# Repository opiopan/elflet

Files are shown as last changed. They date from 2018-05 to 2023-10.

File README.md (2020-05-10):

elflet
====

elflet is a home IoT controller based on [ESP-WROOM-32](https://www.espressif.com/en/products/hardware/modules) (ESP32). <br>
Both of hardware designe and firmware code are open source licenced. 
You are free to use any outcome from this project. And you are also free to modify hardware design and firmware code.<br>
elflet will join your home net work with WiFi.
Then elflet can controll home electronic devices through IR remote controll protocol or Bluetooth LE. 
And this device can be behave as sensor node such as temperature sensor.<br>
Unlike other similar products, elflet highly abstructs IR remote controll protocol. Therefore host-side software to collaborate with elflet is very easy to implement.

<p align="center">
description
</p>

## Features

* **IR receiver**<br>
Receivd IR remote controller signal is analized such as following abstracted protocol data.

    ```json
    {
        "Protocol": "AEHA",
        "BitCount": 160,
        "Data": "11da270002000000000300001000000000000027"
    }
    ```
    Analized protocol data can be retrieved via 
    [REST interface](docs/REST.md), 
    or can be publishd via MQTT protocol.<br>
    **NOTE:** Supported protocols are NEC, SONY, and AEHA.

* **IR transmitter**<br> 
You can transmit IR remote controller signal by specifying the above level abstracted represatation.<br>
elflet supports two protocols for IR transmitter, 
The first one is 
[REST](docs/REST.md)
, and the other one is original binary protocol.
Regarding this binary protocol, please refer 
[these host-side library codes (`irslib.h`, `irslib.c`)](hosttool).

* **Device Shadow**<br>
Device shadow is designed to help complecated IR command device management such as air conditioner.<br>
elflet analize IR command code pattern according to registered shadow definition, then reflect device status to shadow representation managed in elflet. Following JSON data is a example of shadow status representation.
    ```json
    {
        "NodeName": "elflet-living", 
        "ShadowName": "ac",
        "IsOn": true,
        "Attributes":{
            "Mode": "Cooler",
            "Temperature": 26.5,
            "Humidity": 50
        }
    }
    ```

    Shadow status can be refered via 
    [REST interface](docs/REST.md), and status change of shadow device can be known immediately as publicshed data via MQTT.<br>
    You can also change shadow's status by sending the above format data to elflet via 
    [REST interface](docs/REST.md). 
    In this case, elflet synthesize IR code acording to shadow definition then transmit that.<br>
    A couple of shadow definition examples are shown at
    [here](examples).

* **BLE Keyboard Emulator**<br>
elflet can behave as Bluetooth LE (BLE) keyboard. You can send any key code to a device paired with elflet via Bluetooth LE.<br>
The typical use case of this function is to wake up a PC or server which does not accept WOL packet.

* **Environment Sensor**<br>
Following sensors are installed on elflet.
    * temperature sensor
    * humidity sensor
    * atmospheric pressure sensor
    * luminocity sensors

    You can retrieve sensor values via
    [REST interface](docs/REST.md),
    and can also receive them periodically as MQTT published message.<br>
    elflet supports a SENSOR-ONLY mode to avoid own heat affecting to measuring temperature. In this mode, elflet stays in deep sleep status except when sensor values is captured and they are published.
    You can transit elflet to SENSOR-ONLY mode by using
    [host tool](hosttool).

## PCB
PCB of elfet is designed by using [AUTODESK EAGLE](http://eagle.autodesk.com).
* PCB design files are placed [here](pcb/mainboard)
* You can also use [this gerver data](https://raw.githubusercontent.com/wiki/opiopan/elflet/pcb/elflet-mainboard.zip)
for production
* BOM list is [here](pcb/elflet-bom.xlsx?raw=true)

## Building Firmware
Firmware source codes are placed at 
[here](firmware).
To build firmware binary, please refer 
[this document](firmware/README.md).

## Inital Firmware Downloading
Once elflet firmware runs on elflet board, you can download firmware binary via WiFi (OTA updating). However, you need to download firmware via UART at first time since OTA updating function does not work yet.<br>
Folowing four binary files must be download at correct address in ESP-WROOM-32's SPI flash.

|file to download | adress  |
|:---|---:|
| firmware/buld/bootloader/bootloader.bin| 0x1000|
| firmware/buld/partitions.bin | 0x8000|
| firmware/build/ota_data_initial.bin | 0xd000|
| firmware/buld/elflet.bin |  0x10000|
| firmware/buld/spiffsimage.bin | 0x3f0000|

elflet exports sevelal ESP32 pins to service port as below. You can download firmware by connection your USB serial dongle to there.

<p align="center">
description
</p>

Another way to download firmware is using 
[this jig board](https://raw.githubusercontent.com/wiki/opiopan/elflet/pcb/elflet-jig.zip)
and Raspberry Pi. 
[These tools running on Raspberry Pi](raspitools)
may help you to download or debug elflet firmware.<br>
When use this jig board, please connect following direction.

<p align="center">
description
</p>

## Configuration
When initial firmware downloading finish, LED on elflet starts to blink orange. In this state, elflet is working as WiFi access point and it provides Web based setup widzard interface.<br>
The SSID is same as node name of elflet, 
and the initial node name is "`elflet-000000`". Passphrase to connect elflet WiFi access point is same as administorator password, and the initial password is "`elflet00`".
Please connect to elflet WiFi access point by specifing these SSID and passphrase<br>

Once you connect to elflet WiFi access point, you can access to setup widzard. <br>
Since this wizard behaves as same mechanism of [captive portal](https://en.wikipedia.org/wiki/Captive_portal), typical OS shows that wizard window automatically when you connect to elflet WiFi access point.<br>
If no wizard window is shown, try a URL "```http://elflet.setup/```"

**NOTE:** Initial node name and initial administorator password can be change in step of building firmware. Please refer
[this document](firmware/README.md)
regarding the detail. 

<p align="center">
description
</p>

By this wizard, you can configure following items:

* WiFi SSID and passphrase to connect
* elflet node name
* administorator password

When the wizard is completed, elflet restarts and LED start to blink white.
After that, elflet connect to your home network if configuration is correct, and LED turns off.<br>
If WiFi configuration is not correct and elflet cannot connect to your home network in 30 seconds, elflet will fall back to CONFIGURATION mode.
In this case, the LED start to blink orange again and you can access setup Wizard.

During elflet is connecting to your home network, setup widzard is not available. If you want to access setup wizard, please transit elflet to CONFIGURATION mode. You can proceed this transition by pressing a button till LED start to blink orange.

To change other detail configuration, please use a host tools, "`elflet-config`" and "`elflet-shadow`". Usage of these tools are described in [this document](hosttool/README.md).

## Licencing



elflet is released under dual open source licence.<br>
[The elfle firmware](firmware)
is in accordance with 
[GNU General Public License, version 2](https://www.gnu.org/licenses/old-licenses/gpl-2.0.en.html).
The other program source files, PCB design, and all documents are coverd by
[Apache License 2.0](http://www.apache.org/licenses/LICENSE-2.0).

## Application Example
My another project [Wakeserver](https://github.com/opiopan/wakeserver) is a good example of elfelt's application.

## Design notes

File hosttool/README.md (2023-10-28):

elfet Host Tools
===

There are CLI tools to controll elflet as below:

- **elfelt-config**: configure elflet
- **elfelt-shadow**: manage and controll device shadow
- **irtx**: send IR remote controll command

## Requirements
- **Mac or Linux**
- **Python 3**<br>
    ```
    $ python3 --version
    Python 3.7.16
    ```
- **requests** <br>
    ```
    $ pip3 install requests
    ```

## How to install
```
$ make
$ sudo make install
```

## Usage
Run each command with `--help` option. It will show syntax and option's descritption.

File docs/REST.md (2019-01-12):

elflet REST specification
===
**NOTE:** This document is under construction. All interfaces are listed, however descriptions are still insufficient.

## Management

method | path | auth|req-body | resp-body | description
:----|:------:|:-------------:|:------------:|:-------------:|:-----------
GET|/manage/config|none|-|application/json| get elflet configuration
POST|/manage/config|digest|appliation/json|-| change elfelt configuration
GET|/manage/status|none|-|applilcation/json|get statistics and status
POST|/manage/otaupdate|digest|multipart/form|-|update firmware.<br>firmware image is sent as `image` parameta in multipart form.

## IR remote controller
method | path | auth|req-body | resp-body | description
:----|:------:|:-------------:|:------------:|:-------------:|:-----------
GET|/irrc/startReceiver|none|-|-| If `IrrcReceiverMode` parameter of configuration is `OnDemand`, elflet start to receive IR remote controller signal. You can confirm elflet is in this mode as blinking LED blue.<br>If `IrrcReceiverMode` parameter is `Continuous`, This request is ignored.
GET|/irrc/receivedData|none|-|application/json| get latest received IR remote controller code
POST|/irrc/send|none|application/json|-|sedn IR remote controller command

## Device Shadow
method | path | auth|req-body | resp-body | description
:----|:------:|:-------------:|:------------:|:-------------:|:-----------
GET|/shadowDefs|none|-|application/json|list registerd shadow names
GET|/shadowDefs/\<*NAME*>|none|-|application/json|show shadow definition
POST|shadowDefs/\<*NAME*>|digest|application/json|-|add shadow definition
DELETE|shadowDefs/\<*NAME*>|digest|-|-|remove shadow definition
GET|/shadow|none|-|application/json|list registerd shadow names
GET|/shadow/\<*NAME*>|none|-|application/json|get shadow status
POST|/shadow/\<*NAME*>|none|application/json|-|change shadow status

## Sensor

method | path | auth|req-body | resp-body | description
:----|:------:|:-------------:|:------------:|:-------------:|:-----------
GET|/sensor|none|-|application/json| get sonsors value

## BLE keyboard emuration
method | path | auth|req-body | resp-body | description
:----|:------:|:-------------:|:------------:|:-------------:|:-----------
POST|/blehid|none|application/json|-| send key code to a device which paired with elflet BLE keyboard

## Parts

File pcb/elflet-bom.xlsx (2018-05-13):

elflet main board BOM
Label | Attribute | Product id | Quantity | Recommended Seller | URL
U1 | ESP32 module | ESP-WROOM-32 | 1 | Akizuki | http://akizukidenshi.com/catalog/g/gM-11647/
U2 | 3,3V 1A LDO | ADP3338AKCZ-3.3 | 1 |  | http://akizukidenshi.com/catalog/g/gI-12635/
U3 | IR reciever module | OSRB38C9AA | 1 |  | http://akizukidenshi.com/catalog/g/gI-04659/
U4 | Environment sensor | BME280 | 1 | AliExpress | https://www.aliexpress.com/wholesale?SearchText=BME280+chip
Q1 | Nch MOS-FET | IRLML6344TRPBF | 1 | Akizuki | http://akizukidenshi.com/catalog/g/gI-06049/
Q2 | Photo transistor | ALS-PT19-315C/L177/TR8 | 1 | Marutsu | https://www.marutsu.co.jp/GoodsListNavi.jsp?path=&q=ALS-PT19-315C%2FL177%2FTR8
LED1, LED2 | PLCC-2/IR LED | OSI5LAS1C1A | 2 | Akizuki | http://akizukidenshi.com/catalog/g/gI-06427/
LED3 | PLCC-6/Full Color LED | OSTBABS4C2B | 1 |  | http://akizukidenshi.com/catalog/g/gI-06117/
J1 | Micro USB female connector | ZX62-B-5PA(33) | 1 |  | http://akizukidenshi.com/catalog/g/gC-11183/
J2 | low hight pin socket | 2212S-10G-36 | 1 |  | http://akizukidenshi.com/catalog/g/gC-03138/
J3 | NC | - | - | -
SW1 | SMD tact switch | SKRPACE010 | 1 | Akizuki | http://akizukidenshi.com/catalog/g/gP-06185/
C1 | 3216/1uF/25V(+80-20%) | ECJ(L(3))FF1E105Z | 1 |  | http://akizukidenshi.com/catalog/g/gP-08708/
C2 | 3216/4.7uF/16V(+80-20%) | GRM31MF11C475ZA01 | 1 |  | http://akizukidenshi.com/catalog/g/gP-04661/
C3, C5, C8, C9 | 1608/0.1uF/25V(10%) | GRM188B11E104KA01 | 4 |  | http://akizukidenshi.com/catalog/g/gP-05616/
C4, C6 | 1608/10uF/25V(20%) | GRM188R61E106MA | 2 |  | http://akizukidenshi.com/catalog/g/gP-07768/
C7 | 3216/47uF/6.3V(10%) | GRM31CB30J476ME18 | 1 |  | http://akizukidenshi.com/catalog/g/gP-02058/
R1, R2, R3, R6, R10, R14 | 2012/10K/0.1W(0.1%) | AR05BTC1002 | 6 | Sengoku | https://www.sengoku.co.jp/mod/sgk_cart/detail.php?code=EEHD-0HUG
R4, R5 | 1608/4.7K/0.063W/(0.1%) | AR03BTC4701 | 2 |  | https://www.sengoku.co.jp/mod/sgk_cart/detail.php?code=EEHD-0GXT
R7 | 6331/3.3/1W(5%) | RK73BW3ATTE3R3J | 1 |  | https://www.sengoku.co.jp/mod/sgk_cart/detail.php?code=EEHD-0ETM
R8 | 1608/22K/0.063W(0.1%) | AR03BTC2202 | 1 |  | https://www.sengoku.co.jp/mod/sgk_cart/detail.php?code=EEHD-0GYD
R9 | 1608/47/0.063W(0.1%) | AR03BTC0470 | 1 |  | https://www.sengoku.co.jp/mod/sgk_cart/detail.php?code=EEHD-0GW7
R11, R12 | 2012/33/0.1W(0.1%) | AR05BTC0330 | 2 |  | https://www.sengoku.co.jp/mod/sgk_cart/detail.php?code=EEHD-0HSF
R13 | 2012/220/0,1W(0.1%) | AR05BTC2200 | 1 |  | https://www.sengoku.co.jp/mod/sgk_cart/detail.php?code=EEHD-0HT5
R15 | Array 100/0.063W(5%) | BCN164AB101J7 | 1 |  | https://www.sengoku.co.jp/mod/sgk_cart/detail.php?code=6AXT-E7J2
elflet jig BOM
Label | Attribute | Product id | Quantity | Recommended Seller | URL
 | low height pin connector | PH-1x40SG/9.54 | 1 | Akizuki | http://akizukidenshi.com/catalog/g/gC-00171/
 | L type narrow 10 pin header | PHA-1x10RG | 2 |  | http://akizukidenshi.com/catalog/g/gC-06362/
 | 2x20 female pin socket | 2214S-40G-85 | 1 |  | http://akizukidenshi.com/catalog/g/gC-09717/
 | 10 pin female dupont cable | - | 1 | DIY or AliExpress

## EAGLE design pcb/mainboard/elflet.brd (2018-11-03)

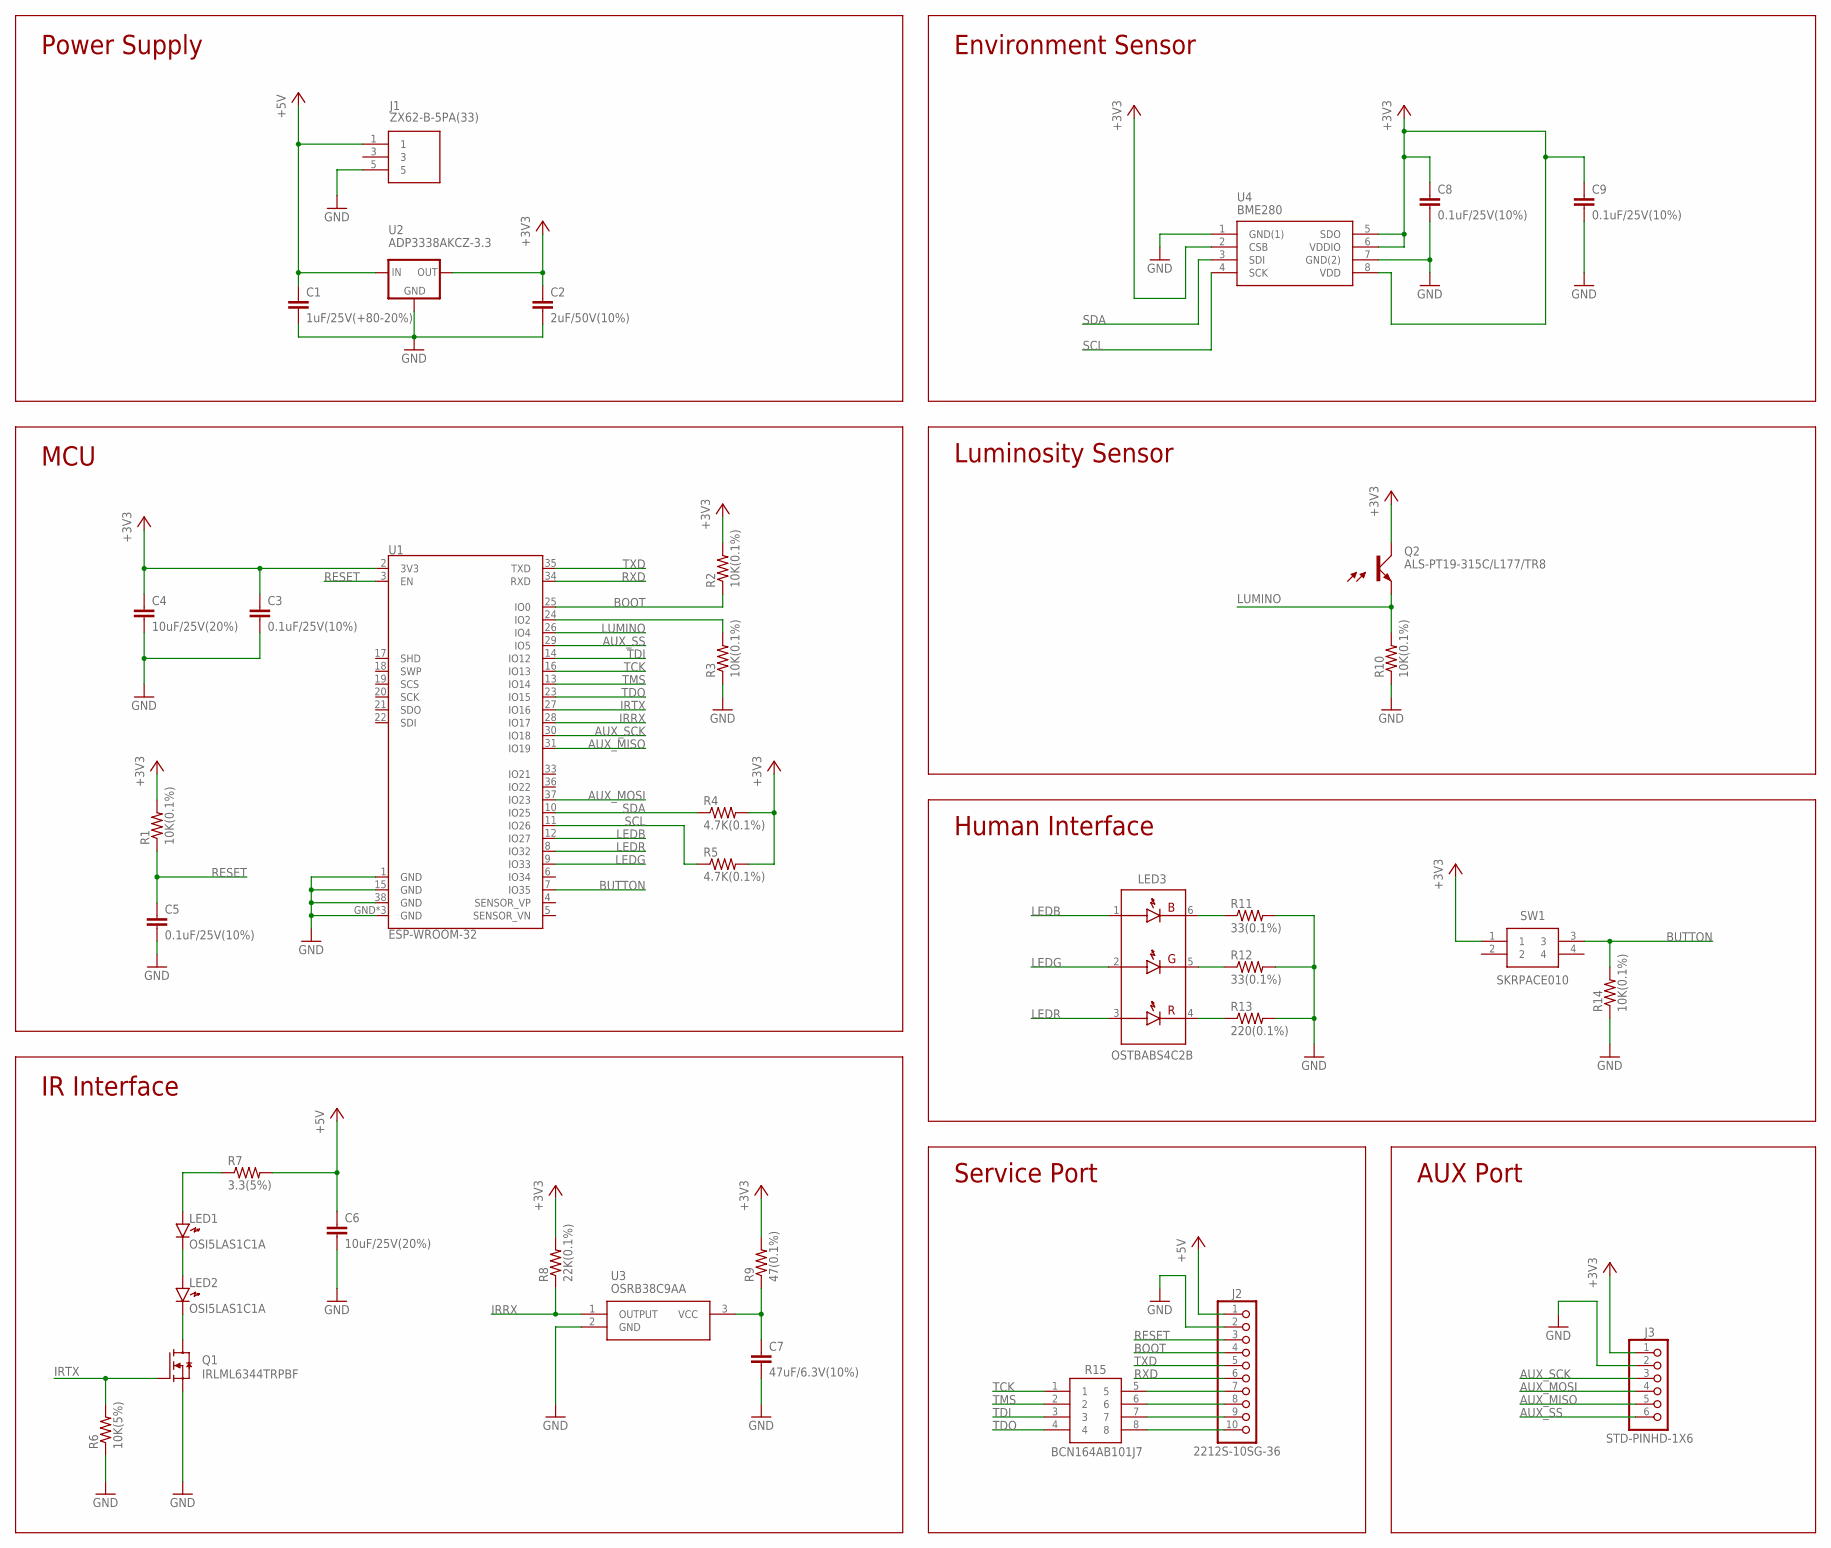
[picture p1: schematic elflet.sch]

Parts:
C1: 1uF/25V(+80-20%); C3216
C2: 2uF/50V(10%); C3216
C3, C5, C8, C9: 0.1uF/25V(10%); C1608
C4, C6: 10uF/25V(20%); C1608
C7: 47uF/6.3V(10%); C3216
J1: ZX62-B-5PA(33); ZX62-B-5PA(33)-TRUE-HANDSOLD
J2: 2212S-10SG-36; STD-1X10
J3: STD-PINHD-1X6; STD-1X6
LED1, LED2: OSI5LAS1C1A; PLCC-2
LED3: OSTBABS4C2B
Q1: IRLML6344TRPBF; SOT23
Q2: ALS-PT19-315C/L177/TR8; ALSPT19315CL177TR8
R1, R2, R3, R10, R14: 10K(0.1%); R0805
R4, R5: 4.7K(0.1%); R0603
R6: 10K(5%); R0805
R7: 3.3(5%); R2512
R8: 22K(0.1%); R0603
R9: 47(0.1%); R0603
R11, R12: 33(0.1%); R0805
R13: 220(0.1%); R0805
R15: BCN164AB101J7; BCN164A_1
SW1: SKRPACE010; SMT(4.2X3.2)
U1: ESP-WROOM-32; ESP-WROOM-03
U2: ADP3338AKCZ-3.3; SOT223
U3: OSRB38C9AA; OSRB38C9AA-ALT
U4: BME280

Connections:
+3V3: C2.1, C3.1, C4.1, C8.1, C9.1, J3.1, Q2.1 (C), R1.2, R2.2, R4.2, R5.2, R8.2, R9.2, SW1.1, U1.2 (3V3), U2.2 (OUT), U2.4 (OUT), U4.2 (CSB), U4.5 (SDO), U4.6 (VDDIO), U4.8 (VDD)
+5V: C1.1, C6.1, J1.1, J2.1, R7.2, U2.3 (IN)
AUX_MISO: J3.5, U1.31 (IO19)
AUX_MOSI: J3.4, U1.37 (IO23)
AUX_SCK: J3.3, U1.30 (IO18)
AUX_SS: J3.6, U1.29 (IO5)
BOOT: J2.4, R2.1, U1.25 (IO0)
BUTTON: R14.2, SW1.3, U1.7 (IO35)
GND: C1.2, C2.2, C3.2, C4.2, C5.2, C6.2, C7.2, C8.2, C9.2, J1.5, J2.2, J3.2, Q1.2 (S), R3.1, R6.1, R10.1, R11.2, R12.2, R13.2, R14.1, U1.1 (GND), U1.15 (GND), U1.38 (GND), U1.GND, U1.GND_B (GND), U1.GND_V (GND), U2.1 (GND), U3.2 (GND), U4.1 (GND(1)), U4.7 (GND(2))
IRRX: R8.1, U1.28 (IO17), U3.1 (OUTPUT)
IRTX: Q1.1 (G), R6.2, U1.27 (IO16)
LEDB: LED3.1 (AB), U1.12 (IO27)
LEDG: LED3.2 (AG), U1.9 (IO33)
LEDR: LED3.3 (AR), U1.8 (IO32)
LUMINO: Q2.2 (E), R10.2, U1.26 (IO4)
unnamed: R3.2, U1.24 (IO2)
unnamed: LED1.1 (K), LED2.2 (A)
unnamed: LED2.1 (K), Q1.3 (D)
unnamed: LED1.2 (A), R7.1
unnamed: C7.1, R9.1, U3.3 (VCC)
unnamed: J2.7, R15.5
unnamed: J2.8, R15.6
unnamed: J2.9, R15.7
unnamed: LED3.6 (KB), R11.1
unnamed: LED3.5 (KG), R12.1
unnamed: LED3.4 (KR), R13.1
unnamed: J2.10, R15.8
RESET: C5.1, J2.3, R1.1, U1.3 (EN)
RXD: J2.6, U1.34 (RXD)
SCL: R5.1, U1.11 (IO26), U4.4 (SCK)
SDA: R4.1, U1.10 (IO25), U4.3 (SDI)
TCK: R15.1, U1.16 (IO13)
TDI: R15.3, U1.14 (IO12)
TDO: R15.4, U1.23 (IO15)
TMS: R15.2, U1.13 (IO14)
TXD: J2.5, U1.35 (TXD)

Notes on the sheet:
MCU
Power Supply
IR Interface
Environment Sensor
Luminosity Sensor
Human Interface
Service Port
AUX Port

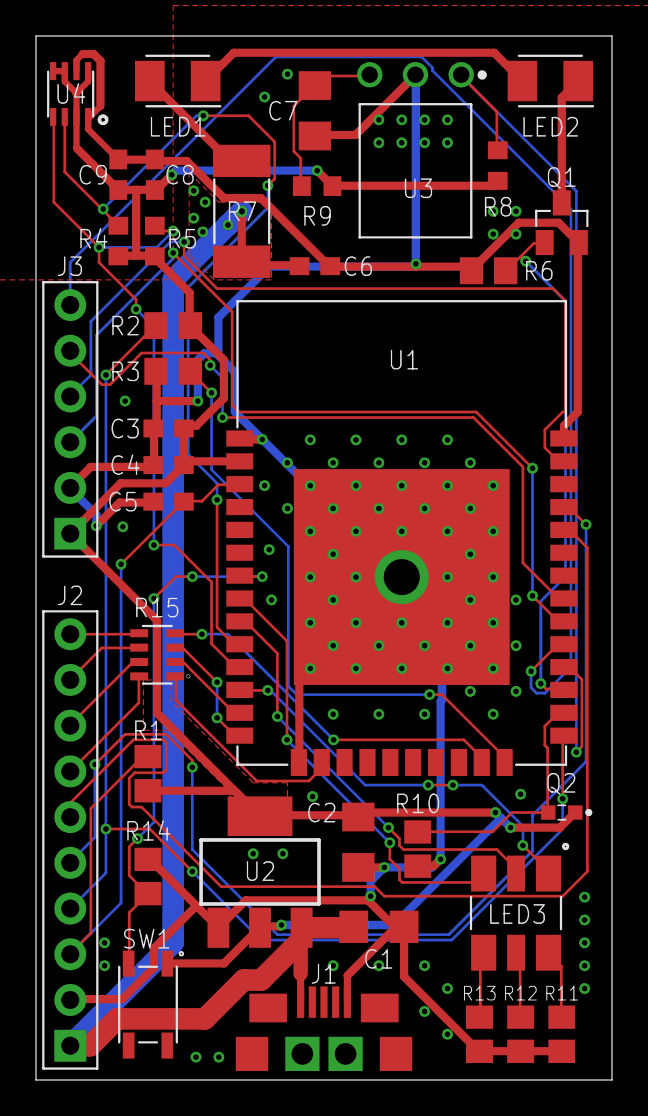
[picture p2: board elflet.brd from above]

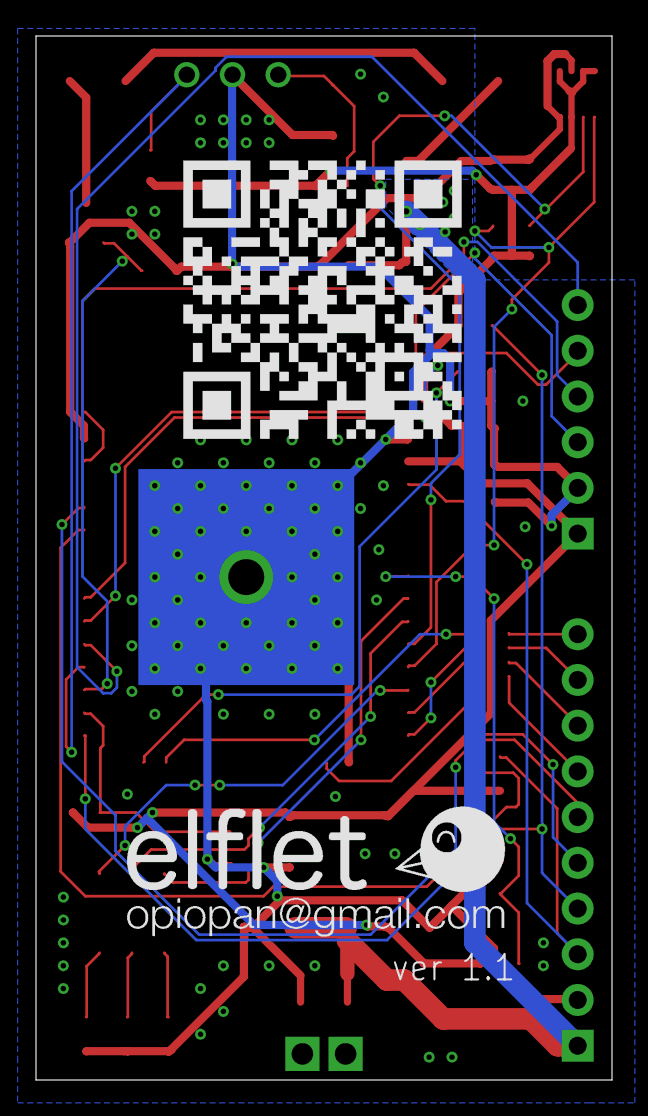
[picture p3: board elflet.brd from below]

Board: 2 copper layers, 32.0 x 58.0 mm, 39 parts (2 on the bottom side), 36 nets.

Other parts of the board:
U$1: ELFLET-LOGO
U$2: ELFLET-QRCODE

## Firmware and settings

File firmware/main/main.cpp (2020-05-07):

#include <esp_log.h>
#include <Task.h>
#include <esp_bt.h>
#include "Config.h"
#include "mdnsService.h"
#include "WifiService.h"
#include "WifiApService.h"
#include "WebService.h"
#include "irserver.h"
#include "LEDService.h"
#include "ButtonService.h"
#include "IRService.h"
#include "SensorService.h"
#include "TimeService.h"
#include "PubSubService.h"
#include "Stat.h"
#include "BleHidService.h"
#include "WatchDog.h"

#include "boardconfig.h"
#include "sdkconfig.h"

static const char tag[] = "main";

_Noreturn static void systemFault(){
    ledSetBlinkMode(LEDBM_SYSTEM_FAULT);
    while (true){
        vTaskDelay(1000 / portTICK_PERIOD_MS);
    }
}

static void showBanner(){
    printf(
        "\033[96m"
        "========================================"
        "========================================\n"
        "        Home IoT controller based on ESP-WROOM-32\n\n"
        "                      ___       ___  ___           __\n"
        "                     /\\_ \\    /'___\\/\\_ \\         /\\ \\__\n"
        "                   __\\//\\ \\  /\\ \\__/\\//\\ \\      __\\ \\ ,_\\ \n"
        "                 /'__`\\\\ \\ \\ \\ \\ ,__\\ \\ \\ \\   /'__`\\ \\ \\/ \n"
        "                /\\  __/ \\_\\ \\_\\ \\ \\_/  \\_\\ \\_/\\  __/\\ \\ \\_ \n"
        "                \\ \\____\\/\\____\\\\ \\_\\   /\\____\\ \\____\\\\ \\__\\ \n"
        "                 \\/____/\\/____/ \\/_/   \\/____/\\/____/ \\/__/ \n\n"
        "        Fiemware Version: %s\n"
        "        Author:           Hiroshi Murayama <opiopan@gmail.com>\n"
        "        Web:              http://github.com/opiopan/elflet/\n"
        "========================================"
        "========================================\n"
        "\033[0m",
        getVersionString());
}

class MainTask : public Task {
    void run(void *data) override;
};

void MainTask::run(void *data){
    updateWatchDog();

    //--------------------------------------------------------------
    // initialize UI LED
    //--------------------------------------------------------------
    startLedService();

    //--------------------------------------------------------------
    // load configuration
    //--------------------------------------------------------------
    if (!initConfig()){
        // nothing to do since serious situation
        systemFault();;
    }

    auto wakeupCause = elfletConfig->getWakeupCause();
    if (wakeupCause != WC_NOTSLEEP){
        baseStat.deepSleepCount++;
        ESP_LOGI(tag, "wakeup from deep sleep by %s",
                 wakeupCause == WC_TIMER ? "time out" : "pushing a button");
    }
    auto mode = elfletConfig->getBootMode();
    ESP_LOGI(tag, "elflet goes to mode: %s",
             mode == Config::FactoryReset ? "FACTORY RESET" :
             mode == Config::Configuration ? "CONFIGURAtiON" :
             "NORMAL");
    if (mode == Config::Configuration){
        elfletConfig->setBootMode(Config::Normal);
        elfletConfig->commit();
    }
    auto isSensorOnly =
        (elfletConfig->getFunctionMode() == Config::SensorOnly);
    auto enableBLE = 
        (wakeupCause == WC_NOTSLEEP && mode == Config::Normal &&
         elfletConfig->getBleHid());

    //--------------------------------------------------------------
    // release memory for Bluetooth if it's possible
    //--------------------------------------------------------------
    if (!enableBLE){
        releaseBleResource();
        auto heapSize = xPortGetFreeHeapSize();
        if (initialHeapSize < heapSize){
            initialHeapSize = heapSize;
            ESP_LOGI(tag, "initial heap size increase to %d bytes", heapSize);
        }
    }
    vTaskDelay(1000 / portTICK_PERIOD_MS);

    //--------------------------------------------------------------
    // start peripheral services
    //--------------------------------------------------------------
    startTimeService();
    startButtonService();
    if (wakeupCause != WC_BUTTON){
        if (!isSensorOnly){
            startIRService();
        }
        startSensorService();
        if (wakeupCause == WC_TIMER){
            enableSensorCapturing();
        }
    }
    
    //--------------------------------------------------------------
    // start network services
    //--------------------------------------------------------------
    if (mode == Config::FactoryReset || mode == Config::Configuration){
        ledSetDefaultMode(
            mode == Config::FactoryReset ? LEDDM_FACTORY_RESET :
                                           LEDDM_CONFIGURATION);
        if (!startWifiApService()){
            systemFault();
        }
        startWebService();
    }else if (!elfletConfig->getWifi()){
        ledSetDefaultMode(LEDDM_BOOT_ONLY_BLE);
        initBleHidService(elfletConfig->getNodeName().c_str());
        startBleHidService();
        vTaskDelay(5000 / portTICK_PERIOD_MS);
        ledSetDefaultMode(LEDDM_STANDBY);
    }else{
        if (wakeupCause == WC_NOTSLEEP){
            ledSetDefaultMode(LEDDM_SCAN_WIFI);
        }else if (wakeupCause == WC_BUTTON){
            ledSetBlinkMode(LEDBM_RESTRICT_DEEP_SLEEP);
        }
        if (elfletConfig->getPubSubServerAddr().length() > 0 &&
            wakeupCause != WC_BUTTON){
            startPubSubService();
        }
        if (!startWifiService()){
            systemFault();
        }
        if (!isSensorOnly || wakeupCause == WC_BUTTON){
            startWebService();
        }
        if (!isSensorOnly){
            startIRServer();
        }
        if (enableBLE){
            initBleHidService(elfletConfig->getNodeName().c_str());
            startBleHidService();
        }
    }

    //--------------------------------------------------------------
    // survey watch dog timer
    //--------------------------------------------------------------
    if (mode == Config::Configuration){
        while (true){
            if (getWatchDogTimerInterval() > 10 * 60){
                ESP_LOGI(tag, "go back to normal mode");
                esp_restart();
            }
            vTaskDelay(1000 / portTICK_PERIOD_MS);
        }
    }
}

extern "C" void app_main() {
    initialHeapSize = xPortGetFreeHeapSize();
    showBanner();
    ESP_LOGI(tag, "free heap size: %d", initialHeapSize);
    auto task = new MainTask;
    task->setStackSize(15000);
    task->start();
}

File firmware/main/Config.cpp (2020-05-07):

#include <esp_log.h>
#include <esp_system.h>
#include <esp_spiffs.h>
#include <nvs_flash.h>
#include <nvs.h>
#include <sys/stat.h>
#include <stdio.h>
#include <iostream>
#include <fstream>
#include <GeneralUtils.h>
#include <CPPNVS.h>
#include <json11.hpp>
#include "Config.h"
#include "ShadowDevice.h"
#include "BleHidJson.h"

#include "boardconfig.h"
#include "sdkconfig.h"

static const char tag[] = "Config";

static const int32_t CONFIG_VERSION = 3;

static const char NVS_NS[] = "elflet";
static const std::string BOOTMODE_KEY = "bootmode";
static const std::string CONFIGGEN_KEY = "configgen";
static const std::string OTACOUNT_KEY = "otacount";

static const char SPIFFS_LABEL[] = "spiffs";
static const char SPIFFS_MP[] = "/spiffs";
static const char VERIFICATION_KEY_PATH[] = "/spiffs/verificationkey.pem";
static const char SHADOW_DEFS_PATH[] = "/spiffs/shadowdefs.json";
static const char TMP_SHADOW_DEFS_PATH[] = "/spiffs/shadowdefs_tmp.json";
static const char SHADOW_STATUS_PATH[] = "/spiffs/shadowstat.json";
static const char* CONFIGPATH[] = {
    "/spiffs/pdata.json",
    "/spiffs/config01.json",
    "/spiffs/config02.json"
};

static const int MAX_NODENAME_LEN = 32;
static const int MAX_PASSWORD_LEN = 64;

const char* Config::defaultTimezone = "JST-9";

Config* elfletConfig = NULL;
static Config* backupedConfig = NULL;
size_t initialHeapSize = 0;

//----------------------------------------------------------------------
// initialize global configuration
//----------------------------------------------------------------------
bool initConfig(){
    // retrieve wakeup cause
    auto wakeupCause = initDeepSleep();
    
    // Initialize NVS
    esp_err_t err = nvs_flash_init();
    if (err == ESP_ERR_NVS_NO_FREE_PAGES) {
        // NVS partition was truncated and needs to be erased
        // Retry nvs_flash_init
        err = nvs_flash_erase();
        if (err != ESP_OK){
            ESP_LOGE(tag, "failed to erase nvs: %s",
                     GeneralUtils::errorToString(err));
            return false;
        }
        err = nvs_flash_init();
    }
    if (err != ESP_OK){
        ESP_LOGE(tag, "failed to initialize nvs: %s",
                 GeneralUtils::errorToString(err));
        return false;
    }

    // mount spiffs
    esp_vfs_spiffs_conf_t conf = {
      .base_path = SPIFFS_MP,
      .partition_label = SPIFFS_LABEL,
      .max_files = 5,
      .format_if_mount_failed = false
    };
    err = esp_vfs_spiffs_register(&conf);
    if (err != ESP_OK){
        ESP_LOGE(tag, "failed to mount spiffs partition: %s",
                 GeneralUtils::errorToString(err));
        return false;
    }
    
    // load configuration
    elfletConfig = new Config(wakeupCause);
    backupedConfig = new Config(wakeupCause);
    return elfletConfig->load();
}

void backupConfig(){
    *backupedConfig = *elfletConfig;
}

void restoreConfig(){
    *elfletConfig = *backupedConfig;
}

//----------------------------------------------------------------------
// Config object initialize / deinitialize
//----------------------------------------------------------------------
Config::Config(WakeupCause cause) :
    fromStorage(false), isDirtyBootMode(false), isDirty(false),
    wakeupCause(cause),
    configVersion(0),
    functionMode(FullSpec), sensorFrequency(0), 
    pubSubSessionType(SessionTCP), irrcReceiverMode(IrrcReceiverOnDemand),
    wifi(true), bleHid(false), buttonMode(BLEHID_KEYCODE){
}

Config::~Config(){
}

Config& Config::operator = (const Config& src){
    otaCount = src.otaCount;
    bootMode = src.bootMode;
    wakeupCause = src.wakeupCause;
    fileGeneration = src.fileGeneration;
    configVersion = src.configVersion;
    functionMode = src.functionMode;
    boardVersion = src.boardVersion;
    nodeName = src.nodeName;
    apssid = src.apssid;
    adminPassword = src.adminPassword;
    ssidToConnect = src.ssidToConnect;
    wifiPassword = src.wifiPassword;
    ntpServer = src.ntpServer;
    timezone = src.timezone;
    sensorFrequency = src.sensorFrequency;
    pubSubServerAddr = src.pubSubServerAddr;
    pubSubSessionType = src.pubSubSessionType;
    pubSubServerCert = src.pubSubServerCert;
    pubSubUser = src.pubSubUser;
    pubSubPassword = src.pubSubPassword;
    sensorTopic = src.sensorTopic;
    irrcReceiveTopic = src.irrcReceiveTopic;
    irrcReceivedDataTopic = src.irrcReceivedDataTopic;
    irrcSendTopic = src.irrcSendTopic;
    downloadFirmwareTopic = src.downloadFirmwareTopic;
    shadowTopic = src.shadowTopic;
    irrcReceiverMode = src.irrcReceiverMode;
    wifi = src.wifi;
    bleHid = src.bleHid;
    buttonMode = src.buttonMode;
    buttonBleHidCode = src.buttonBleHidCode;

    return *this;
}
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

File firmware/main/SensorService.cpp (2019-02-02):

#include <esp_log.h>
#include <esp_system.h>
#include <string.h>
#include <iostream>
#include <GeneralUtils.h>
#include <Task.h>
#include <freertos/event_groups.h>
#include "Mutex.h"
#include "TimeObj.h"
#include "Config.h"
#include "SensorService.h"
#include "bme280.h"
#include "PubSubService.h"
#include "Stat.h"

#include "boardconfig.h"
#include "sdkconfig.h"

static const char tag[] = "SensorService";

class SensorTask;
static SensorTask* sensorTask;

//----------------------------------------------------------------------
// Sensor observation task
//----------------------------------------------------------------------
class SensorTask : public Task {
protected:
    static const int EV_WAKE_SERVER = 1;
    EventGroupHandle_t events;
    Mutex mutex;
    
    BME280_I2C* bme280;

    int enableFlag;
    Time captureTime;

    int32_t temperature;
    int32_t humidity;
    int32_t pressure;
    uint32_t luminosity;

public:
    SensorTask();
    virtual ~SensorTask();

    void enableCapture();
    void getValue(SensorValue* value);

protected:
    void run(void *data) override;
};

SensorTask::SensorTask() : enableFlag(0){
    events = xEventGroupCreate();

    bme280 = new BME280_I2C(0x77,
                            (gpio_num_t)GPIO_I2C_SDA, (gpio_num_t)GPIO_I2C_SCL,
                            I2C::DEFAULT_CLK_SPEED,
                            I2C_NUM_0, false);
    bme280->init();
}

SensorTask::~SensorTask(){
    delete bme280;
}

void SensorTask::enableCapture(){
    xEventGroupSetBits(events, EV_WAKE_SERVER);
}

void SensorTask::getValue(SensorValue* value){
    LockHolder holder(mutex);
    value->enableFlag = enableFlag;
    value->temperature = temperature;
    value->humidity = humidity;
    value->pressure = pressure;
    value->luminosity = luminosity;
}

void SensorTask::run(void *data){
    xEventGroupWaitBits(events, EV_WAKE_SERVER,
                        pdTRUE, pdFALSE,
                        portMAX_DELAY);

    int workingSensors = 0;
    if (bme280->isWorking()){
        workingSensors = 
                SensorValue::TEMPERATURE |
                SensorValue::HUMIDITY |
                SensorValue::PRESSURE;
    }
    
    while (true){
        if (bme280->isWorking()){
            bme280->start(true);
            vTaskDelay(100 / portTICK_PERIOD_MS);
            bme280->measure();
            Time now;
            sensorStat.bme280CaptureCount++;
        }

        {
            LockHolder holder(mutex);
            enableFlag = workingSensors;
            temperature = bme280->getTemperature();
            humidity = bme280->getHumidity();
            pressure = bme280->getPressure();
        }

        publishSensorData();
        
        /*
        printf("%s Temp[%.1f dig] Hum[%.1f %%] Press[%.1f hPa]\n",
               now.format(Time::SIMPLE_DATETIME),
               bme280->getTemperatureFloat(),
               bme280->getHumidityFloat(),
               bme280->getPressureFloat());
        */

        vTaskDelay(
            elfletConfig->getSensorFrequency() * 1000 / portTICK_PERIOD_MS);
    }

    while (true){
    }
};

//----------------------------------------------------------------------
// interfaces for outer module
//----------------------------------------------------------------------
bool startSensorService(){
    if (!sensorTask){
        sensorTask = new SensorTask();
        sensorTask->start();
    }

    return true;
}

void enableSensorCapturing(){
    if (sensorTask){
        sensorTask->enableCapture();
    }
}

void getSensorValue(SensorValue* value){
    if (sensorTask){
        sensorTask->getValue(value);
    }
}

void getSensorValueAsJson(std::ostream& out){
    if (!sensorTask){
        return;
    }
    
    SensorValue value;
    getSensorValue(&value);

    bool first = true;
    auto sep = [&]() -> void {
        if (first){
            first = false;
        }else{
            out << ",";
        }
    };

    out << "{";
    sep();
    out << "\"" << JSON_NODENAME << "\":\""
        << elfletConfig->getNodeName() << "\"";
    if (value.enableFlag != 0){
        sep();
        out << "\"" << JSON_DATE << "\":\""
            << value.captureTime.format(Time::RFC1123) << "\"";
    }
    if (value.enableFlag & SensorValue::TEMPERATURE){
        sep();
        out << "\"" << JSON_TEMP_UNIT << "\":\"celsius\",\""
            << JSON_TEMP << "\":"
            << value.temperatureFloat();
    }
    if (value.enableFlag & SensorValue::HUMIDITY){
        sep();
        out << "\"" << JSON_HUM_UNIT << "\":\"percentage\",\""
            << JSON_HUM << "\":"
            << value.humidityFloat();
    }
    if (value.enableFlag & SensorValue::PRESSURE){
        sep();
        out << "\"" << JSON_PRESS_UNIT << "\":\"hPa\",\""
            << JSON_PRESS << "\":"
            << value.pressureFloat();
    }
    out << "}";
}

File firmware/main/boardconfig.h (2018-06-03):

#pragma once

#include "version.h"

#define GPIO_BUTTON   35
#define GPIO_LEDR     32
#define GPIO_LEDG     33
#define GPIO_LEDB     27
#define GPIO_IRLED    16
#define GPIO_IRRX     17
#define GPIO_I2C_SDA  25
#define GPIO_I2C_SCL  26
#define GPIO_LUMINO   4
#define GPIO_AUX_SCK  18
#define GPIO_AUX_MISO 19
#define GPIO_AUX_MOSI 23
#define GPIO_AUX_SS   5

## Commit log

2018-04-19 place all parts on a board
    [elflet.brd, elflet.sch]
2018-04-22 initial wiring
    [elflet.brd, elflet.sch]
2018-04-22 add jig board pcb design
    [elflet-bom.xlsx, elflet-jig.brd, elflet-jig.sch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]
2018-04-23 add logo silk
    [elflet.brd]
2018-04-29 optimized for panerizing
    [elflet.brd]
2018-04-29 add panelize script
    [elflet.brd]
2018-05-01 improved data & tools for panelizing
    [dimension.brd]
2018-05-03 improve panelizing
    [dimension.brd, elflet.brd]
2018-05-13 fix usb connector issue
    [elflet-bom.xlsx, elflet.brd, elflet.sch]
2018-05-27 add firmware code base
    [elflet.brd, partitions.csv]
2018-05-31 add WiFi AP mode in factory reset status and configuration status, adn add OTA update feature
    [Config.cpp, main.cpp]
2018-06-03 implement LED indicator feature
2018-06-03 supported button interface
2018-06-04 fix button bug
2018-06-06 fix a LED fade bug
    [LEDService.cpp]
2018-06-10 add a feature which can be retrieve sensor values via REST
2018-06-10 improve sensor capturering function to detect if bme280 is installed or not
2018-06-10 add tools to use in raspberry pi environment
    [esp32.cfg, raspi-jtag.cfg]
2018-06-27 add publish sensor value function
2018-07-01 add Sensor-Only mode which works in deep sleep status except publishing sensor data
2018-07-21 prepare to implement a downloading firmware when mqtt message issued
    [raspi-jtag.cfg]
2018-07-24 add OTA update capability issued via mqtt
    [DeepSleep.cpp]
2018-07-28 fix a bug that long IR comand could not be sent
    [DeepSleep.cpp]
2018-08-18 add device shadow function
2018-08-26 add user defined attribute to device shadow
2018-08-28 fix issues related user defined attribute in device shadow and optimize stack size of each task
    [ButtonService.cpp, LEDService.cpp, main.cpp]
2018-08-28 fix a problem that retrying to connect to MQTT broaker never succeed in case of the broaker does not work when elflet boot
2018-08-30 fix a bug that topic name for shadow status could not be changed
    [Config.cpp]
2018-09-02 prepare to imprement synthesizing function for device shadow
2018-09-04 add IR command synthesizing capability to device shadow
2018-09-08 fix a issue that changing mode by holding button will fail
    [ButtonService.cpp]
2018-10-21 improve PCB design to support fusion360 relation
    [elflet-jig.brd, elflet.brd, elflet.sch]
2018-11-03 fix a issue of shows status serialization
    [elflet.brd]
2018-12-19 update for 3d model
    [elflet-jig.brd, elflet-jig.sch]
2018-12-25 improve reliability in sensor only mode
2018-12-26 improve accuracy of RTC in SensorOnly mode
2018-12-29 fix a minor issue
    [main.cpp]
2018-12-31 add shadow definition samples
2019-02-02 replace tab code as space
    [partitions.csv]
2019-02-03 improve debug environment on Raspberry Pi
    [esp32-raspi1.cfg, esp32-raspi2.cfg, esp32.cfg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]
2020-01-04 fix a issue that 100% of CPU cycle is consumed in setup mode
    [main.cpp]
2020-04-30 prepare to support a function that send BLE HID code by pressing a button
2020-05-03 add a function sending HID code via BLE when button on elflet is pressed
2020-05-04 tuned timing of initalizing each device
2020-05-17 rewrited BLE keyboard emulation code based on new exsample code using esp-hid component
    [esp32-raspi1.cfg, esp32-raspi2.cfg]
2020-07-01 update scripts for Raspberry Pi
    [esp32-raspi.cfg, esp32-raspi2.cfg]
2025-05-03 changed a debugging script to adapt to OpenOCD 0.12.0
    [esp32-raspi.cfg]
2025-06-01 Improved the expressiveness of the Device Shadow
2025-06-06 Added support for generating multi-frame IR command
2025-06-07 Improved accuracy of the frame interval for the device shadow IR command synthesising
2025-06-08 Improved the expressiveness of the device shadow definition: It is now possible to specify conditional expressions—equivalent to those used during IR command interpretation—as activation conditions f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
